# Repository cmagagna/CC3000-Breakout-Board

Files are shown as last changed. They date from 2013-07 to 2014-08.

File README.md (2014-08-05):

<h3>This project is abandoned!</h3>

<p>
I've given up on the CC3000, it's just too buggy and problematic.
</p>

<p>TI themselves say this on the CC3000 page:</p>

<pre>
TI recommends CC3200 & CC3100 for all new and existing embedded Wi-Fi & Internet of Things applications.
</pre>

<p>And they've removed references to the CC3000 on their SimpleLink WiFi page at
<a href="http://www.ti.com/ww/en/simplelink_embedded_wi-fi/home.html">http://www.ti.com/ww/en/simplelink_embedded_wi-fi/home.html</a>
</p>

<p>
I'm going to leave these pages here so people searching the web for help don't find dead links,
but I recommend you abandon your quest to make this half-baked module work. Best of luck to you.
</p>

<hr/>
<hr/>
<hr/>

CC3000 Breakout
=============

<p>Version 1.4</p>

<p>Yet another breakout board for the TI CC3000 WiFi module</p>

<p>Based on a design & library by Matt Bigarani, http://www.centerblack.com</p>

<p>This design is licensed under the Creative Commons CC by NC SA (http://creativecommons.org/licenses/by-nc-sa/3.0/us/). OK to share & remix for any noncommercial purpose</p>

<p>The antenna used by Matt from the SparkFun-RF library was the wrong size. SparkFun had one that was close (ANTENNA-CHIP5) but wasn't exactly right so I modified the part in their library. The modified library is included in this project as SparkFun-RF-Modified.lbr</p>
 
<p>Changes:</p>
<ul>
<li>1.4 - Changed antenna trace from 20 mil to 50 mil & antenna trace gap from 12 mil to 10 mil based on calculations from http://chemandy.com/calculators/coplanar-waveguide-with-ground-calculator.htm</li>
<li>1.3 - First board design to be manufactured. Fixed antenna footprint from V1.2</li>
<li>1.2 - Fixed antenna gap per antenna datasheet</li>
<li>1.1 - Revised BOM to use the same parts as TI whenever possible</li>
<li>1.0 - Initial prototype</li>
</ul>

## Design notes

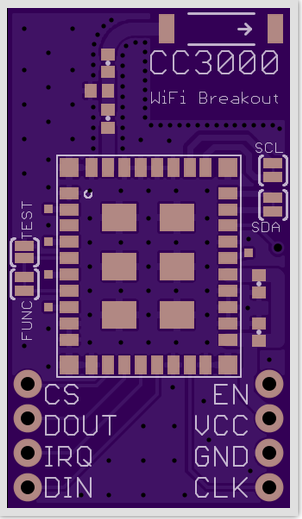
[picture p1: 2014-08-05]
Board.png

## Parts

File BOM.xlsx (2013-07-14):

CC3000 WiFi Breakout Board
bubbletronics.com
Revision 1.0
Bill of Materials
Line | Qty | Description | Manufacturer part # | DigiKey part # | Price ea | Total
1 | 1 | WiFi module | CC3000MODR | 296-35512-1-ND | $12.51 | $12.51
2 | 1 | Chip Antenna | 2500AT44M0400 | 712-1403-1-ND | $1.35 | $1.35
3 | 2 | 1uF cap 0402 X5R 6.3V 10% HF | GRM155R60J105KE19D | 490-1320-1-ND | $0.10 | $0.20
4 | 1 | 10pF cap 0402 50V NPO | CBR04C100J5GAC | 399-6168-1-ND | $0.12 | $0.12
5 | 1 | 2.2pF cap 0402 | UVK105CH2R2JW-F | 587-1015-1-ND | $0.30 | $0.30
6 | 1 | 2.2nH inductor | L-07C2N2SV6T | 712-1414-1-ND | $0.10 | $0.10
 |  |  |  |  | Total | $14.58

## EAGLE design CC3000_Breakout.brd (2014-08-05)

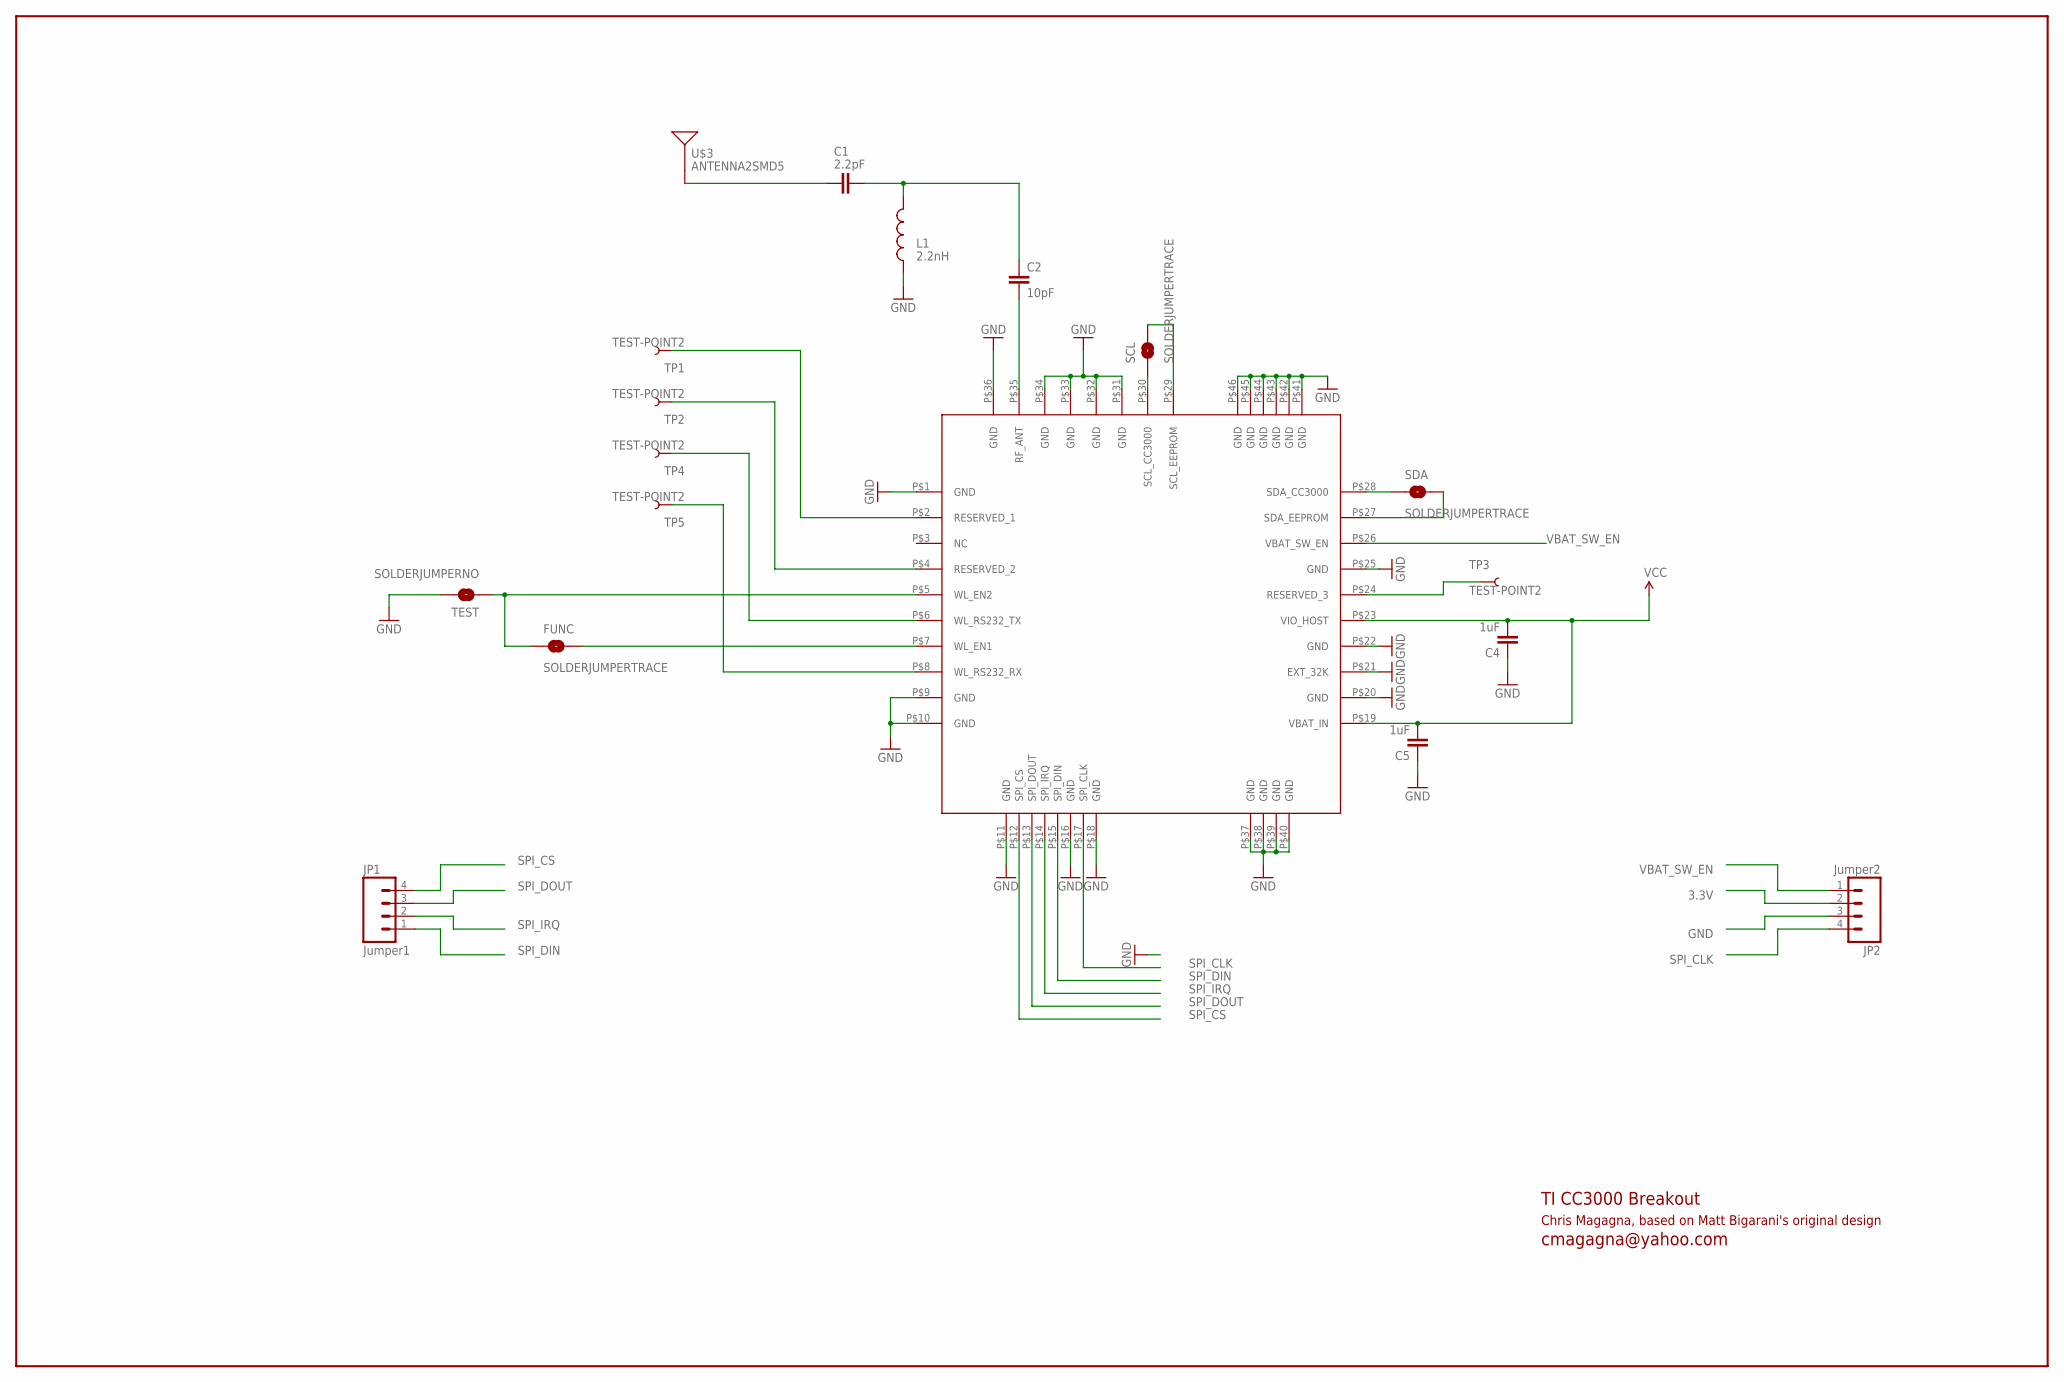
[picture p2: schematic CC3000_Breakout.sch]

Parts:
C1: 2.2pF; 0402-CAP
C2: 10pF; 0402-CAP
C4, C5: 1uF; 0402-CAP
FUNC: SOLDERJUMPERTRACE; SJ_2S-TRACE
JP1: Jumper1; 1X04
JP2: Jumper2; 1X04
L1: 2.2nH; C0402
SCL: SOLDERJUMPERTRACE; SJ_2S-TRACE
SDA: SOLDERJUMPERTRACE; SJ_2S-TRACE
TEST: SOLDERJUMPERNO; SJ_2S-NO
TP1, TP2, TP3, TP4, TP5: TEST-POINT2; PAD.02X.02
U$1: CC3000
U$3: ANTENNA2SMD5; ANTENNA-CHIP5

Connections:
3.3V: C4.2, C5.2, JP2.2, U$1.P$19 (VBAT_IN), U$1.P$23 (VIO_HOST)
GND: C4.1, C5.1, JP2.3, L1.1, TEST.2, U$1.P$1 (GND), U$1.P$9 (GND), U$1.P$10 (GND), U$1.P$11 (GND), U$1.P$16 (GND), U$1.P$18 (GND), U$1.P$20 (GND), U$1.P$21 (EXT_32K), U$1.P$22 (GND), U$1.P$25 (GND), U$1.P$31 (GND), U$1.P$32 (GND), U$1.P$33 (GND), U$1.P$34 (GND), U$1.P$36 (GND), U$1.P$37 (GND), U$1.P$38 (GND), U$1.P$39 (GND), U$1.P$40 (GND), U$1.P$41 (GND), U$1.P$42 (GND), U$1.P$43 (GND), U$1.P$44 (GND), U$1.P$45 (GND), U$1.P$46 (GND)
unnamed: FUNC.2, U$1.P$7 (WL_EN1)
unnamed: FUNC.1, TEST.1, U$1.P$5 (WL_EN2)
unnamed: TP1.P$1, U$1.P$2 (RESERVED_1)
unnamed: TP2.P$1, U$1.P$4 (RESERVED_2)
unnamed: TP4.P$1, U$1.P$6 (WL_RS232_TX)
unnamed: TP5.P$1, U$1.P$8 (WL_RS232_RX)
unnamed: TP3.P$1, U$1.P$24 (RESERVED_3)
unnamed: C1.2, C2.1, L1.2
unnamed: C2.2, U$1.P$35 (RF_ANT)
unnamed: SCL.1, U$1.P$30 (SCL_CC3000)
unnamed: C1.1, U$3.FEED
unnamed: SCL.2, U$1.P$29 (SCL_EEPROM)
unnamed: SDA.1, U$1.P$28 (SDA_CC3000)
unnamed: SDA.2, U$1.P$27 (SDA_EEPROM)
SPI_CLK: JP2.4, U$1.P$17 (SPI_CLK)
SPI_CS: JP1.4, U$1.P$12 (SPI_CS)
SPI_DIN: JP1.1, U$1.P$15 (SPI_DIN)
SPI_DOUT: JP1.3, U$1.P$13 (SPI_DOUT)
SPI_IRQ: JP1.2, U$1.P$14 (SPI_IRQ)
VBAT_SW_EN: JP2.1, U$1.P$26 (VBAT_SW_EN)

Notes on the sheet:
Chris Magagna, based on Matt Bigarani's original design
cmagagna@yahoo.com
TI CC3000 Breakout

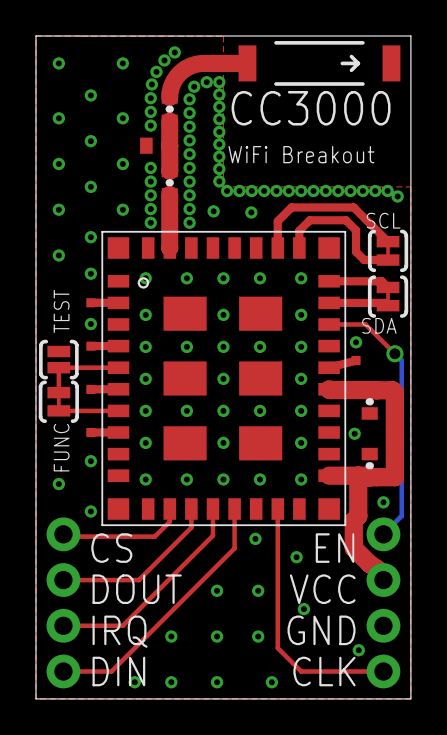
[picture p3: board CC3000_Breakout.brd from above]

Board: 2 copper layers, 20.8 x 36.8 mm, 18 parts (0 on the bottom side), 22 nets.

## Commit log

2013-07-14 Version 1.0.1
    Initial upload
    [CC3000_Breakout.brd, CC3000_Breakout.sch]
2013-07-14 Added BOM
    [BOM.xlsx]
2013-07-14 Added BOM and license
    [CC3000_Breakout.brd]
2013-07-14 Version 1.1
    Removed 2nd (NL) inductor, straightened out antenna trace
    [CC3000_Breakout.brd, CC3000_Breakout.sch]
2013-07-15 Version 1.2
    Changed antenna trace width from 14.4 mil to 20 mil, reworked via
    stitching around antenna gap
    [CC3000_Breakout.brd]
2013-07-15 Version 1.3
    The antenna in Matt's design wasn't the right size, I've fixed the
    antenna footprint to match the actual chip used.
    [CC3000_Breakout.brd, CC3000_Breakout.sch]
2014-08-05 Abandoned project!
    [CC3000_Breakout.brd, CC3000_Breakout.sch]

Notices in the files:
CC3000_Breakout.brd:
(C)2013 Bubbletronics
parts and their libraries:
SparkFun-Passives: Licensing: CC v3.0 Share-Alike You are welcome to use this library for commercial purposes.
